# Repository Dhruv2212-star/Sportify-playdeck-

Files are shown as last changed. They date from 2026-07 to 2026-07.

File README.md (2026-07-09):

# Description- this project was made for controling any media sounds via the spotify playdeck without reopening the application on your desktop  

## The main components required for this build are 
1. mechenical keyboard switches X4 
2. seeed studio XIAO RP2040 X1
3. 0.91 Inch OLED Display X1

## Final schematic should be as following- 
Screenshot (233)

# Update the schematic to PCB and Route the traces 
Screenshot (228)
And once the traces and connections are made, create a rectangle and make sure all the components fit insite it.
IMPORTANT- the rectangle property should be set to "edge.cuts".

# Create the case 

## Bottom case 
Screenshot (229)
## top case  
Screenshot (239)

# ASSEMBELED FILE
this is an model of what your project will look life later 
Screenshot (234)

# you can download all the file from the 'productions' folder 
this way you would escape the trouble of recreating the PCB the case for it and you can build it yourself!!  
Now once you have the files ready, Order the PCB and 3D print the case files  
solder all the components in their places   
hot glue the pcb in the case for extra strength  
# Schematic building 
1. Add these 3 components first-
-MODULE-SEEDUINO-XIAO
-sw_push
-PinHeader_1x04_P2.54mm_Vertical
2. Connect each Sw_push to their own gpio pin, i connected them to D0, D1, D2, D3
3. connect the other part of the Sw_push to Gnd port on the Xiao RP2040  
 **That's it for your switches! now for the LCD**  
4. now on 'PinHeader_1x04_P2.54mm_Vertical' connect pin 1 to GND on the XIAO RP2040, pin2- 3.3v, pin3- D5(SCL), pin4- D4(SDA)
**That's your schematic completed!**  
# PCB tracing
1. select update to PCB
2. select the footprints for each components
3. now click on one trace of the component's pad, this will show you where it supposed to be connected, draw the lines to that region
4. now do this for all the pads present on the PCB and traces them on the PCB  
   **Thats the PCB done!**
# Case 
## Note down the dimesions from the PCB model and start with a simple sketch of a box with your dimentions and, then make the walls to fit the PCB inside then make the top case from the dimensions of the bottom case you just made and cut out the parts you need to from the top case 
# Firmware flashing 
## instal circuitpython   
1. connect your microcontroler to your PC   
2. new drive called RPI-RP2 will appear    
3. paste "adafruit-circuitpython-seeeduino_xiao_rp2040-en_US-10.2.1" file from the 'Firmware' folder given    
4. The board automatically restarts  
5. the drive is now named 'CIRCUITPY'  
6. delete any file named 'code.py' in the CIRCUITPY drive if any  
7. now copy and past these files from the firmware folder  
8. "boot.py", "code.py", entire "lib" folder  
9. yout board should look like this

CIRCUITPY/  

boot.py  

code.py  

lib/  
10. save and close the window and boot it  
# That's it! 
## open spotify and now you can control the pause, play, next, previous funtions without opening your spotify desktop application 

Ai ussage- ai was used to select the correct liberaries for the code and also trouble shooting the schematic. that's it

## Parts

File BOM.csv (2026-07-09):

Item No. | Component Name | Quantity | Price (INR) | Price (USD) | Purchase Link
1 | Seeed Studio XIAO RP2040 Microcontroller Board | 1 | 1350 | 14.18 | https://amzn.in/d/08VoEd5F
2 | 0.91 Inch I2C OLED Display Module (128x32) | 1 | 279 | 2.93 | https://amzn.in/d/0j7gFkEg
3 | Mechanical Keyboard Switches (Pack of 20) | 1 | 359 | 3.77 | https://amzn.in/d/00brGa3T
4 | M3 x 5mm Brass Heat-Set Threaded Insert (Pack) | 1 | 249 | 2.62 | https://amzn.in/d/05o5qIqN
5 | Keycaps (3D Printed - Custom) | 1 | 0 | 0.00 | Self-manufactured (3D printed)
6 | Enclosure/Case (3D Printed - Custom) | 1 | 0 | 0.00 | Self-manufactured (3D printed)
 | TOTAL |  | 2237 | 23.50

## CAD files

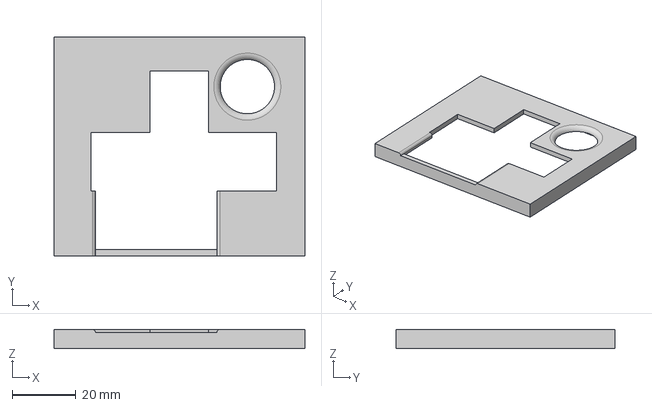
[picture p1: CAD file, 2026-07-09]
CAD/Top case.step
78.6 x 68.6 x 6.00 mm

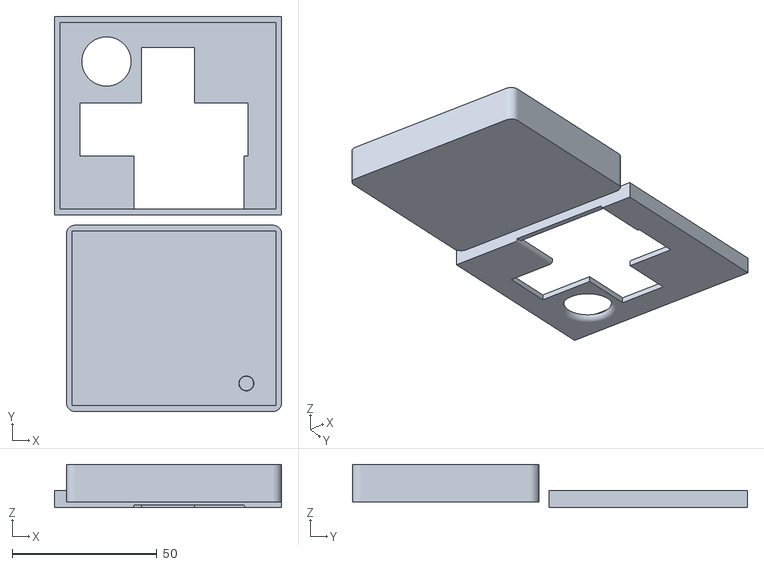
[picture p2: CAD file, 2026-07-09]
PRODUCTION/Final case.stl
78.6 x 136.5 x 15.0

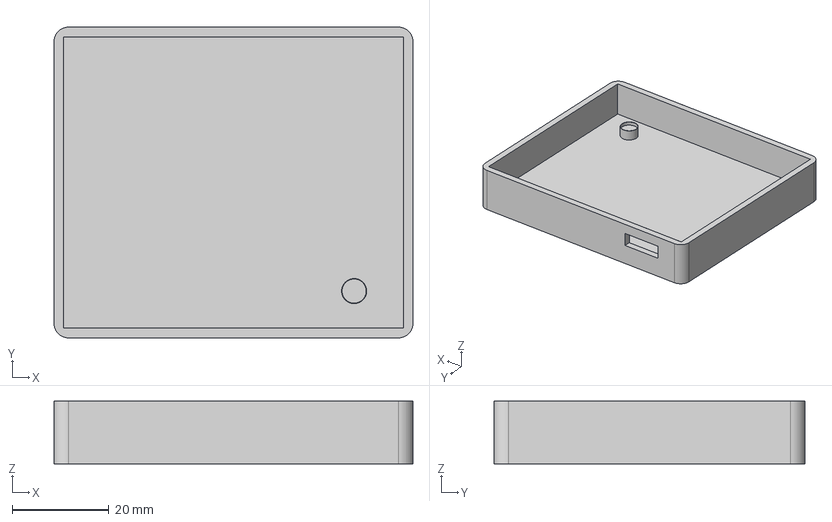
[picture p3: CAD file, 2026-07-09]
CAD/Bottom case.step
74.4 x 64.4 x 13.0 mm

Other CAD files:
CAD/fusion files/Bottom case.f3d
CAD/fusion files/Top case.f3d

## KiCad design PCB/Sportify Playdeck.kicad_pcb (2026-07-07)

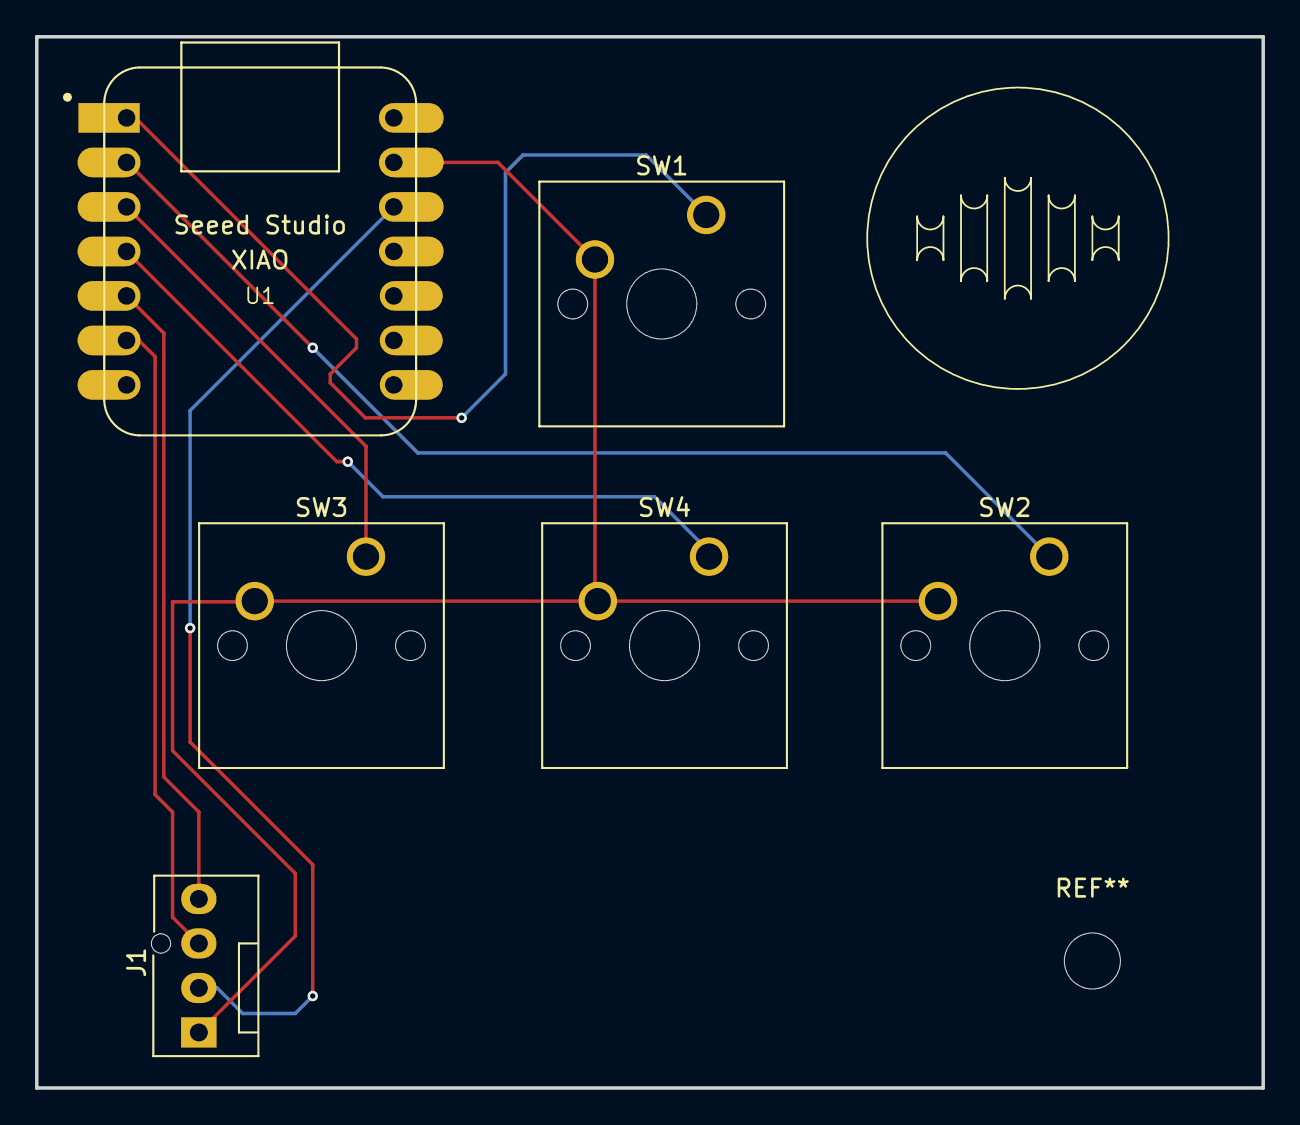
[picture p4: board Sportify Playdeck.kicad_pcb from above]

Board: 2 copper layers, 70.0 x 60.0 mm, 6 parts (0 on the bottom side), 8 nets.

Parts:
J1: Conn_01x04_Pin; FanPinHeader_1x04_P2.54mm_Vertical
SW1, SW2, SW3, SW4: SW_Push; SW_Cherry_MX_1.00u_PCB
U1: MOUDLE-SEEEDUINO-XIAO; XIAO-Generic-Hybrid-14P-2.54-21X17.8MM

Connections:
unnamed: J1.1, SW1.2, SW2.2, SW3.2, SW4.2, U1.13 (GND)
unnamed: J1.2, U1.12 (3V3)
unnamed: J1.3, U1.6 (PA9_A5_D5_SCL)
unnamed: J1.4, U1.5 (PA8_A4_D4_SDA)
unnamed: SW1.1, U1.1 (PA02_A0_D0)
unnamed: SW2.1, U1.2 (PA4_A1_D1)
unnamed: SW3.1, U1.3 (PA10_A2_D2)
unnamed: SW4.1, U1.4 (PA11_A3_D3)

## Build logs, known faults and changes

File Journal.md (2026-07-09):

# KiCAD Schematic Design

## Overview
Started working on schematics in KiCAD, reviewing datasheets for the XIAO RP2040 and IIC 0.91 inch OLED display.

## Progress
-  Completed schematic design
-  **Time taken: 36 minutes** (including datasheet review)

Schematic Design
**Lapse-** https://lapse.hackclub.com/timelapse/cNsDbuVQeTtv
### The data sheet refered to- 


# PCB routing| time taken- 25 Mins
Connect all the wires  
 

https://lapse.hackclub.com/timelapse/HbNP6czxwbrO

# Case making with fusion| 1 hour 40 mins
https://lapse.hackclub.com/timelapse/3T7hJ20QbLii
started with taking the dimentions of the PCB and finalised the sketches and extruded it to make the case 
## Bottom case 


## top case (failed attempt)


## started making the assembly file | Time- 1 hour 30 mins  
https://lapse.hackclub.com/timelapse/fa2zcxGxBGC8 (DUE TO SOME REASON, THE RECORDING DIDN'T START SO THE STARTING PART GOT CUT OUT)
  

**while make the assemble file i realised a small mistake in the PCB and the top case**
1. the pcb header was wrongly rotated
2. the top case had minor dimention errors

# improvements
## Schematic & PCB | time take- 15 mins
so i had to fix the schematic
Screenshot (233)

## Redesigned the Top case and assembly file | time- 1.2hrs 
https://lapse.hackclub.com/timelapse/GK2uGSXP3GSe  
the dimetions i took in the Kicad were slightly off and so i had to take the calculations from the assembly file while constantly taking refrence.  
Screenshot (239)

**Remade the assembly file** 
Screenshot (238)

# Firmware | time- 3 hour 
## did research on funtions i needed and the coorect the libs i needed for that and also had learn the functions of the liberaries to write the code, there were still many errors and it took several tries & misfuntions but in the end the final 'code.py' file was ready

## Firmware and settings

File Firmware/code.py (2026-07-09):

import time
import board
import busio
import keypad
import displayio
import terminalio
import usb_hid

import adafruit_displayio_ssd1306

from adafruit_display_text import label
from adafruit_hid.consumer_control import ConsumerControl
from adafruit_hid.consumer_control_code import ConsumerControlCode




displayio.release_displays()

i2c = busio.I2C(board.D5, board.D4)

display_bus = displayio.I2CDisplay(
    i2c,
    device_address=0x3C
)

display = adafruit_displayio_ssd1306.SSD1306(
    display_bus,
    width=128,
    height=32,
)

splash = displayio.Group()

title = label.Label(
    terminalio.FONT,
    text="Spotify PlayDeck",
    color=0xFFFFFF,
    x=5,
    y=10,
)

status = label.Label(
    terminalio.FONT,
    text="Booting...",
    color=0xFFFFFF,
    x=20,
    y=25,
)

splash.append(title)
splash.append(status)

display.root_group = splash=


time.sleep(2)

status.text = "Ready"



cc = ConsumerControl(usb_hid.devices)


keys = keypad.Keys(
    (
        board.D0,
        board.D1,
        board.D2,
        board.D3,
    ),
    value_when_pressed=False,
    pull=True,
)

print("Spotify PlayDeck Ready")



last_action = time.monotonic()


def show(text):
    global last_action
    status.text = text
    last_action = time.monotonic()


while True:

    event = keys.events.get()

    if event and event.pressed:

        if event.key_number == 0:
            cc.send(ConsumerControlCode.SCAN_PREVIOUS_TRACK)
            show("Previous Track")

        elif event.key_number == 1:
            cc.send(ConsumerControlCode.PLAY_PAUSE)
            show("Play / Pause")

        elif event.key_number == 2:
            cc.send(ConsumerControlCode.VOLUME_INCREMENT)
            show("Volume +")

        elif event.key_number == 3:
            cc.send(ConsumerControlCode.VOLUME_DECREMENT)
            show("Volume -")

    if time.monotonic() - last_action > 3:
        if status.text != "Ready":
            status.text = "Ready"

    time.sleep(0.01)

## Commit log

2026-07-07 Update README with project details and components
    Added initial project components and schematic instructions.
2026-07-07 Insert image in Journal.md
    Added an image to the journal entry.
2026-07-07 Add PCB routing section to Journal.md
    Added section for PCB routing with image.
2026-07-07 Add time taken for PCB routing
    Added time taken for PCB routing section.
2026-07-07 Update README with PCB schematic instructions
    Added instructions for updating the schematic to PCB and routing traces.
2026-07-07 Document case making and assembly process
    Added details about case making process and assembly file.
2026-07-07 Fix PCB errors and update case design
    Corrected PCB header rotation and adjusted top case dimensions. Updated schematic and PCB to reflect changes, and modified case design for an open DIY look.
2026-07-07 Update Journal.md with assembly notes and improvements
    Fixed formatting issues and improved clarity in the Journal.md file. Added time taken for tasks and detailed mistakes found during assembly.
2026-07-07 finished PCB, bottom case
    [.step, Bottom case.f3d, Bottom case.step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]
2026-07-07 Update README with top case and schematic images
    Added top case section and updated schematic images.
2026-07-08 Update instructions for building the project
    Added instructions for ordering PCB and 3D printing case.
2026-07-08 Enhance README with top case image and formatting
    Added image for the top case and improved formatting.
2026-07-08 Add assembled file section to README
    Added a section for the assembled file model with an image.
2026-07-08 Document improvements and redesigns in Journal.md
    Updated the Journal to reflect improvements made to the schematic and redesigned the top case and assembly file.
2026-07-08 Revise schematic and PCB time estimates in Journal
    Updated section titles and corrected time estimates for schematic and PCB improvements.
2026-07-08 Update README with new screenshots and description
    Added a new screenshot for the top case and a description for the assembled file section.
2026-07-09 Add CircuitPython installation instructions
    Added instructions for installing CircuitPython on the microcontroller and controlling Spotify.
2026-07-09 Revise Journal.md with task updates and corrections
    Updated various sections with time taken for tasks and improved formatting. Added notes on mistakes found during assembly.
2026-07-09 updated the schematics, assembly file and firmware
    [.step, Bottom case.f3d, Bottom case.step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]
2026-07-09 added case.stl file for easier productionn
    [Final case.stl]
2026-07-09 Revise Journal with updates and corrections
    Updated time estimates for firmware and assembly file, added links to timelapse videos, and corrected minor errors in PCB and top case dimensions.
2026-07-09 Refine README.md for project documentation and added instructions for schematic
    Updated the README.md for clarity and formatting. Improved component descriptions and added schematic building and PCB tracing instructions.
2026-07-09 Fix typos and enhance PCB tracing instructions
    Corrected spelling errors and improved clarity in PCB tracing instructions.
2026-07-09 bill of material
    the components and their costs & link
    [BOM.csv]
